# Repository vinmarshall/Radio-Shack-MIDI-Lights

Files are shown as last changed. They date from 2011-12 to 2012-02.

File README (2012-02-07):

These files are the plans for the "Radio Shack MIDI Lights" project 
that was featured in the December 2011 issue of Popular Science.  Look at 
the instructions file for more information.

./PCB - Circuit schematic and board layout.  
  Express PCB files plus images of the trace layers and mechanical drawings 
  of the board.

./midi_lights_code - Arduino code

./parts - Bill of Materials and parts sourcing information.

./schematic - The schematic for the circuit.

instructions.pdf - Instructions for building this project.

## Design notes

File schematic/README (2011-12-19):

These files are images of the schematic.  This information is the same as
the PCB/rs_midi_lights.sch file, presented here as a series of images.

Each image corresponds to one page on the schematic.

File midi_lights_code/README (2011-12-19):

Check the github repository for any updates, revisions, or bug fixes.
https://github.com/vinmarshall/Radio-Shack-MIDI-Lights 

midi_lights_code.pde - Arduino code for this project.

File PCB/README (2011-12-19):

The files in this directory pertain to the printed circuit board design.

Even if you don't choose to have your board professionally made, the mechanical
drawings, pictures of component placement, and the PDFs of the board layers
may help you in putting together your own board.  

I had my board made by ExpressPCB (great when you're in a hurry) and the board 
and schematic files here are in their program's format.

pcb_bottom_traces.pdf - The traces on the bottom side of the board.

pcb_components.bmp - How the components are laid out on top of the board.

pcb_dimensions.AD_DRW - Alibre CAD version of the pcb_dimensions.pdf 

pcb_dimensions.pdf - A mechanical drawing of the board with dimensions.

pcb_mechanical.dxf - DXF (2-D CAD) mechanical drawing of the board.

pcb_silkscreen.pdf - The silkscreen layer on top of the board.

pcb_top_traces.pdf - The traces on the top side of the board.

./PCBComponents_Custom - Custom components from this board for the ExpressPCB 
  software.

rs_midi_lights.pcb - ExpressPCB file with the board.

rs_midi_lights.sch - ExpressPCB file with the schematic.

./SchComponents_Custom - Custom components from this circuit for the ExpressPCB 
  software.

./SchSymbols_Custom - Custom symbols from this cicuit for the ExpressPCB software.

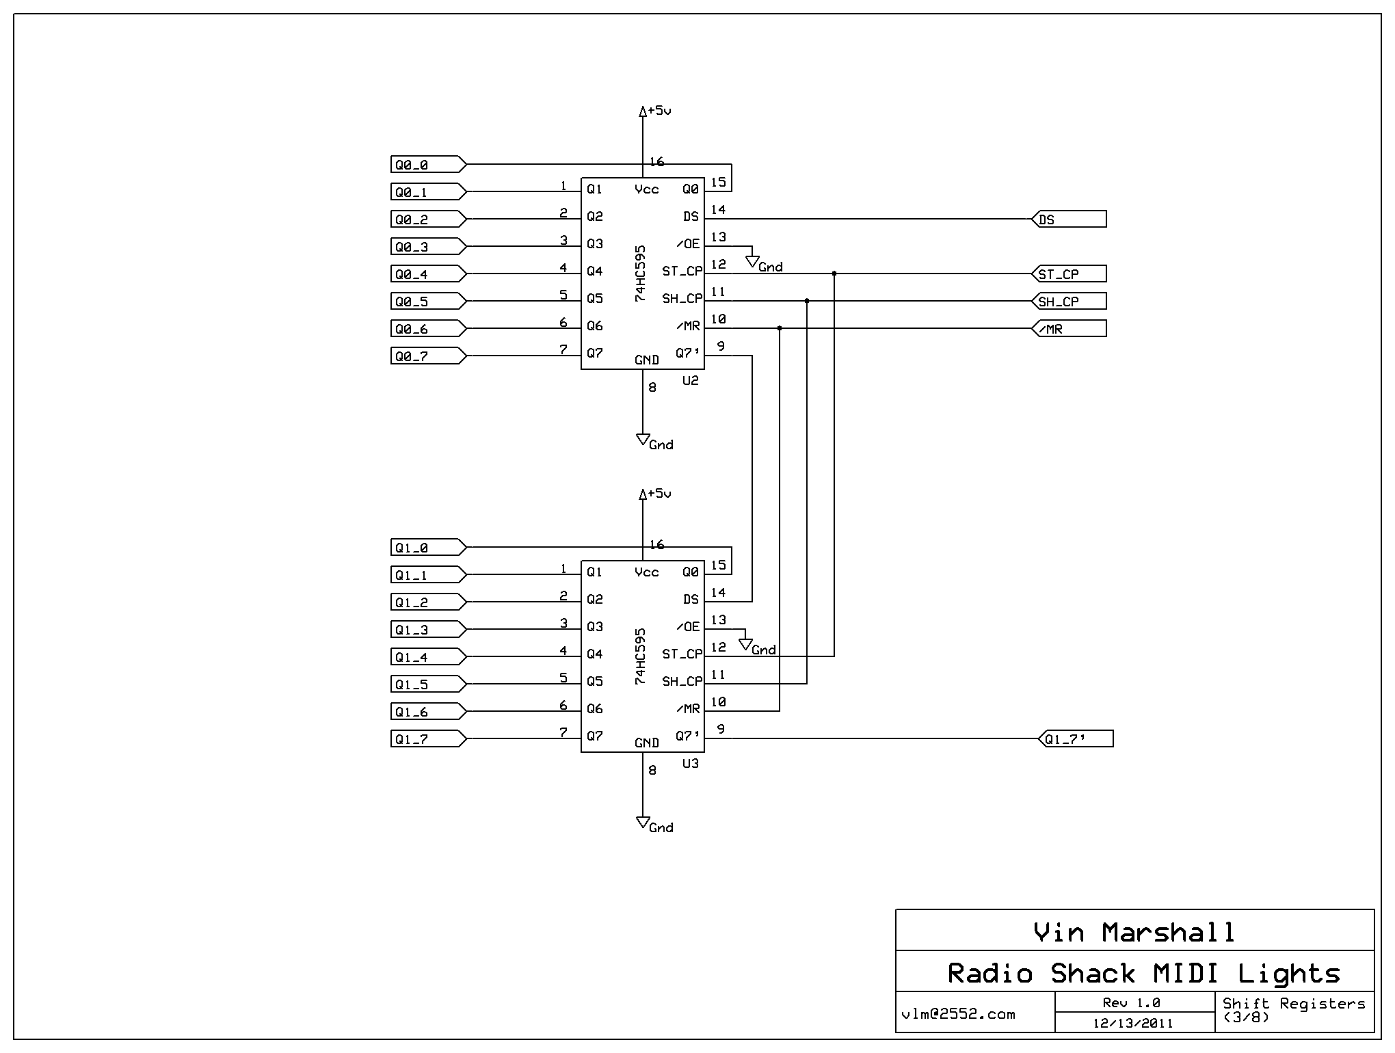
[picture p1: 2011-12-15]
schematic/3_shift_registers.bmp

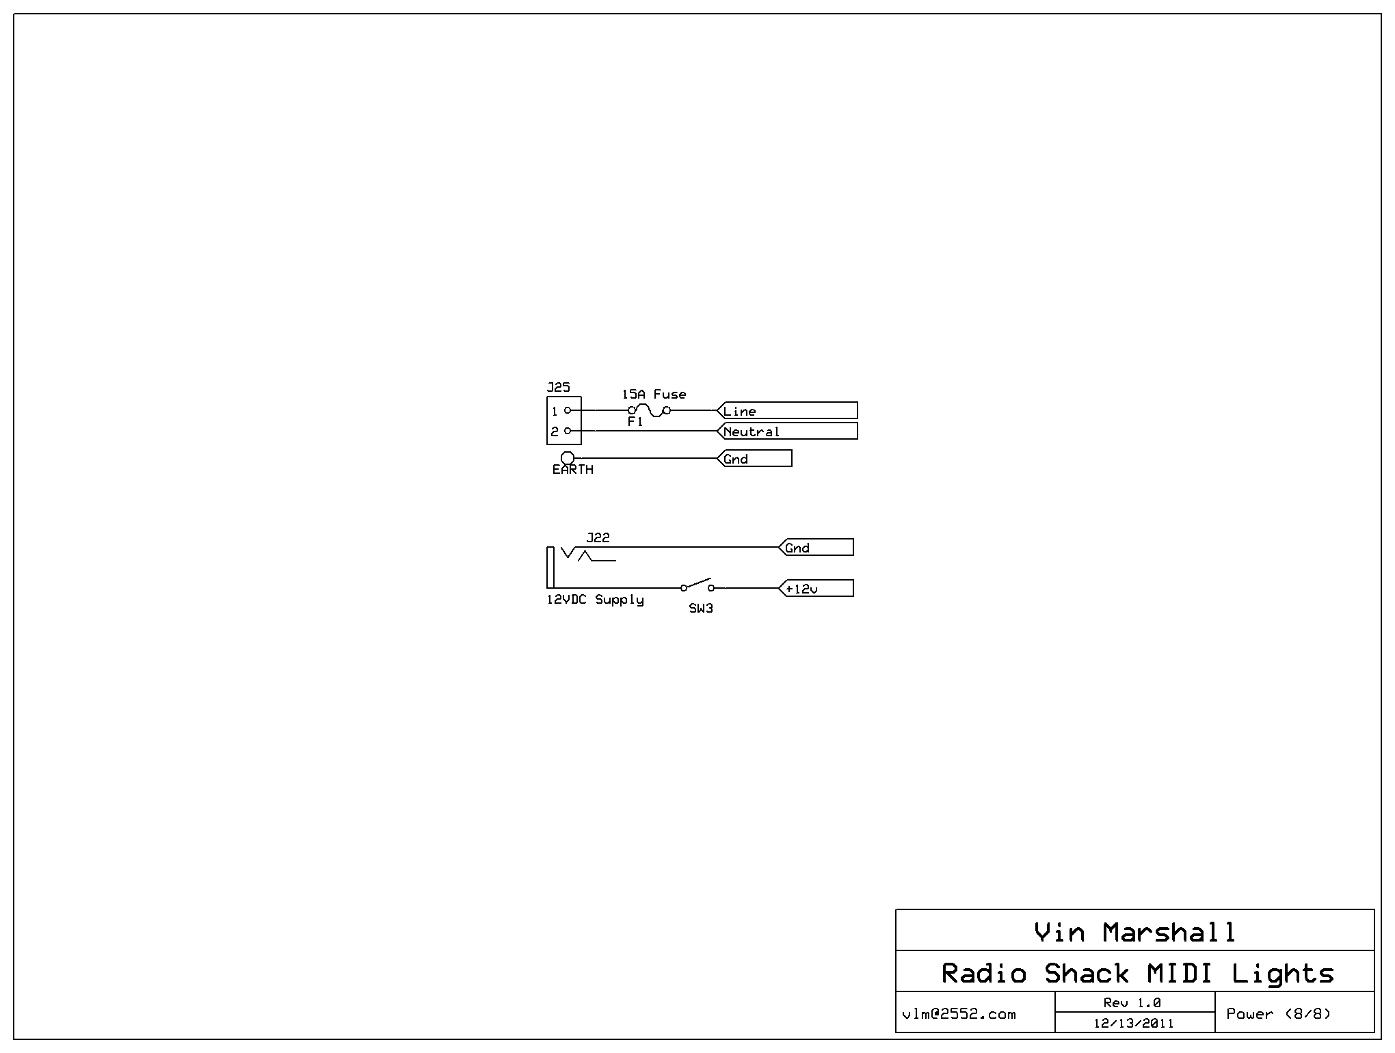
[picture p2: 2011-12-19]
schematic/8_power.bmp

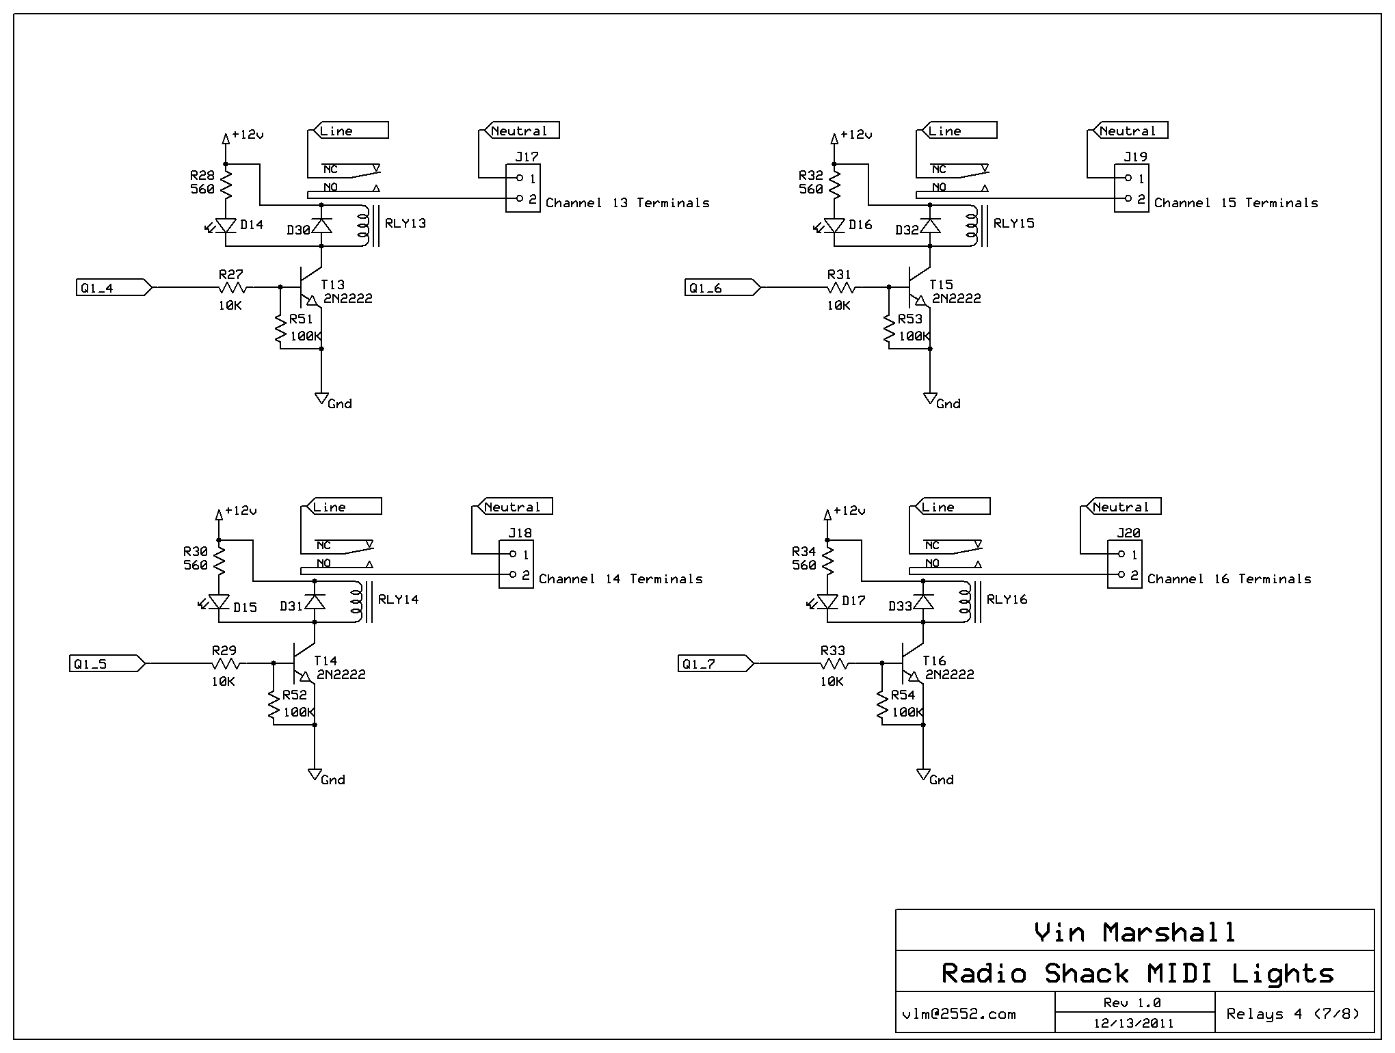
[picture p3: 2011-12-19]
schematic/7_relays_4.bmp

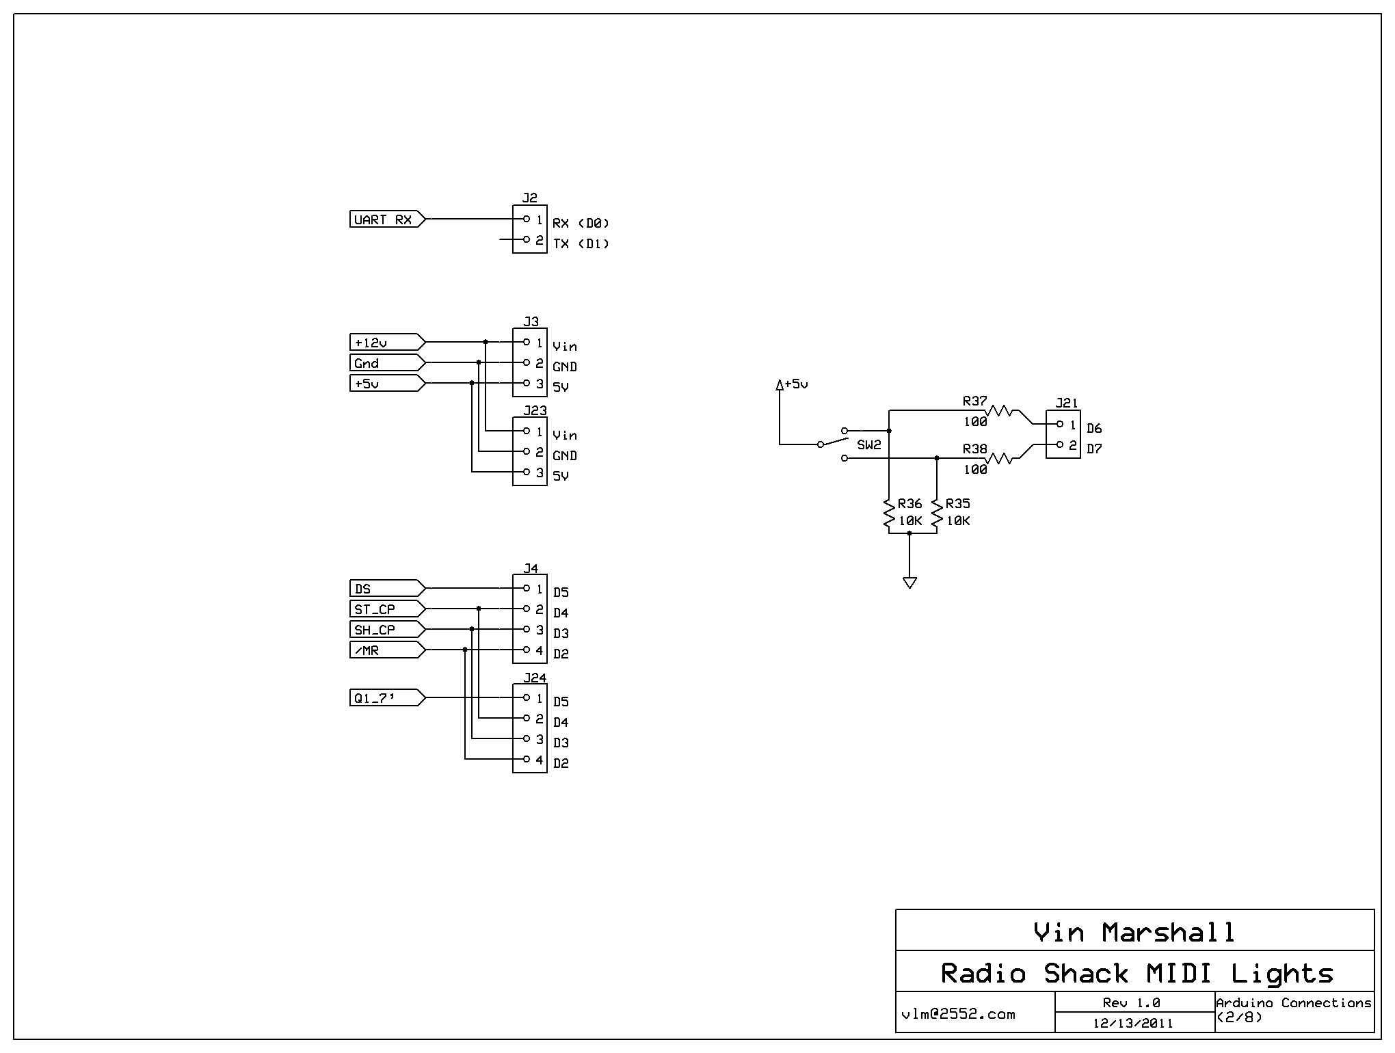
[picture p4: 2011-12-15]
schematic/2_arduino_connections.bmp

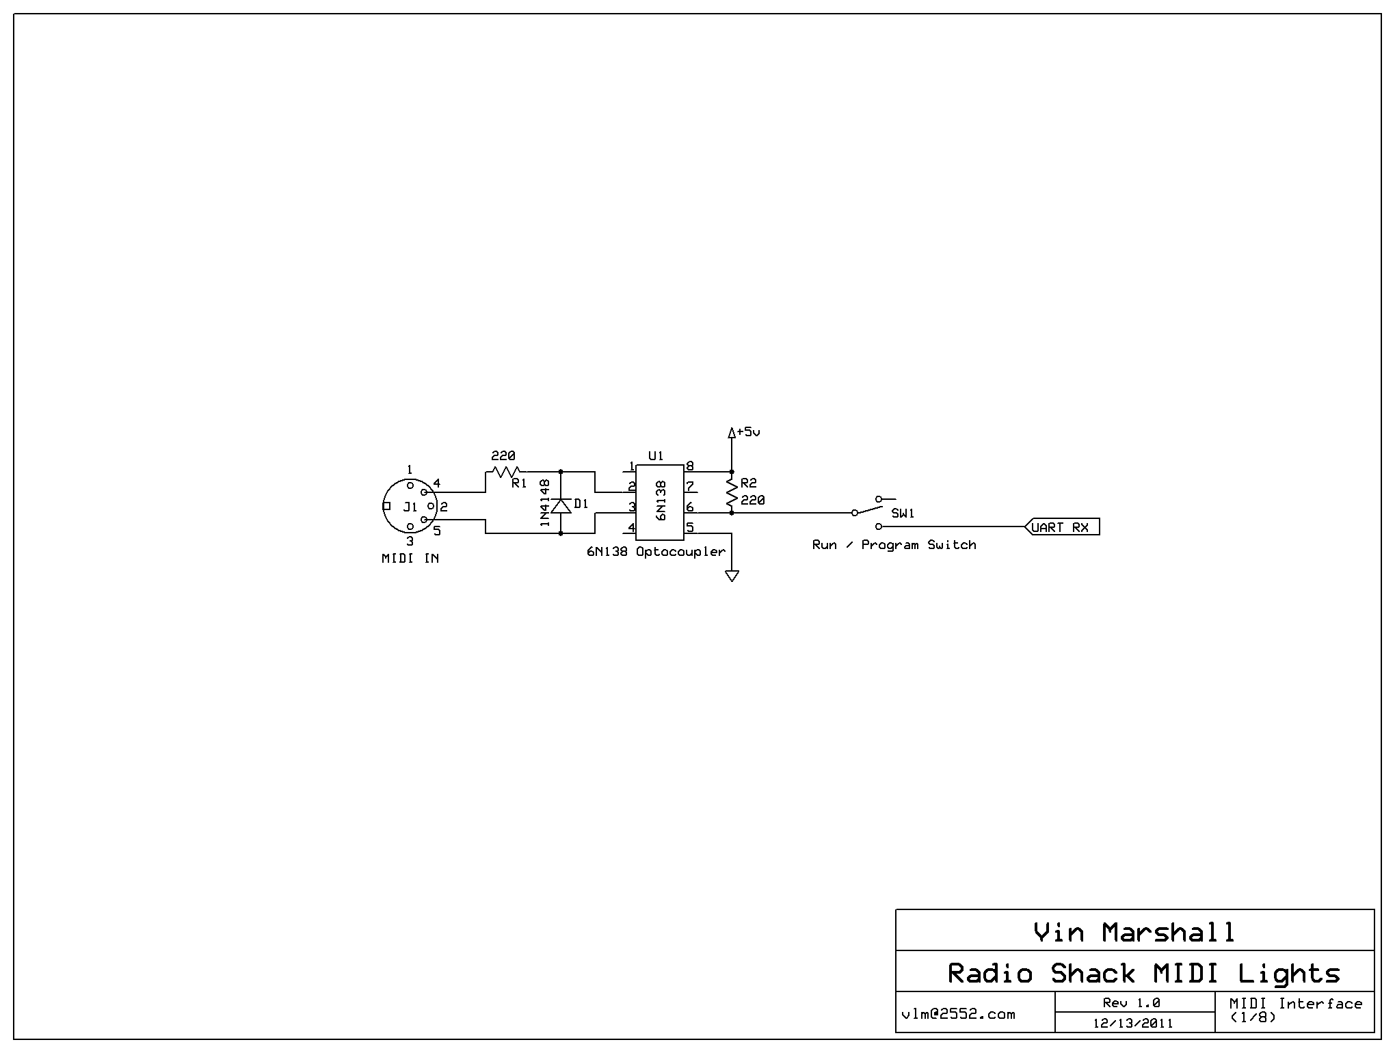
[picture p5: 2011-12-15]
schematic/1_MIDI.bmp

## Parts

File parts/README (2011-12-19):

The files in this directory contain information on sourcing parts for this 
project.  

circuit_board_BOM - A chart correlating part numbers on the schematic and 
  PCB to actual parts.

ordering_BOM - A Bill of Materials for ordering parts for this project.

PCB:

The PCB can be sourced from ExpressPCB.  For a board this big, they're not 
exactly cheap, but they are quick.  You may want to team up with a few other 
people building this circuit, as the unit price quickly goes down with quantity.

Instructions - 
 - Download their software from http://www.expresspcb.com/ if you don't already 
   have it.
 - Open the ./PCB/rs_midi_lights.pcb file
 - From the 'Layout' menu, select "Compute Board Cost" to see your options 
   (Standard or Proto) and then "Order Boards via the Internet" to order.

I've also included PDFs of the top, bottom, and silkscreen layers as well as a 
mechanical drawing of the board and a picture of the component placement which 
should be useful if you are laying out your own PCB or doing point to point 
wiring.

If you are going to doing this with point to point wiring on a perf board, you 
should be able to get this all to fit on 2 of Radio Shack p/n 276-147 - one
board for the relays and one for everything else.

ENCLOSURE:

I haven't specified a specific enclosure for this project, but make sure you 
enclose it completely in something to protect it from contamination, foreign 
objects, hands, etc... - especially if you choose to run 120VAC on the power
busses.  They CANNOT be left exposed.

PARTS:

The ordering_BOM file lists the parts I used to build the circuit and their
sources.  If you don't decide to build the project exactly as I did, the list
should at least give you a head start on your own build.

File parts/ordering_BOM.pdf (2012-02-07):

Sheet1

### Radio Shack MIDI Lights – Ordering Board Bill Of Materials

Quantity Part | Vendor | Part Number
1 | 1N4148 Diode | Radio Shack | 276-1122
8 | Red LED | Radio Shack | 276-0041
8 | 1N4004 Rectifier Diode | Radio Shack | 276-1103
4 | PC Board Terminals | Radio Shack | 276-1388
1 | 100 Ohm 1/4W Resistor | Radio Shack | 276-1311
1 | 220 Ohm 1/4W Resistor | Radio Shack | 271-1313
4 | 560 Ohm, 1/2W Resistor | Radio Shack | 271-1116
4 | 100K Ohm 1/4W Resistor | Radio Shack | 271-1347
5 | 10K Ohm 1/4W Resistor | Radio Shack | 271-1335
16 | 12VDC PC Mount Relay | Radio Shack | 275-241
1 | SPDT Center Off Toggle Switch | Radio Shack | 275-0325
1 | SPST Toggle Switch | Radio Shack | 275-0324
16 | 2N2222 NPN BJT Transistor | Radio Shack | 276-2009
1 | | Radio Shack | 276-128
1 | | Radio Shack | 276-138
1 | | Radio Shack | 273-318
1 | | Radio Shack | 273-342
1 | MIDI Connector | Spark Fun Electronics PRT-09536
1 | 0.1” Pin Headers | Spark Fun Electronics PRT-00116
2 | 2 Pin, 6” Jumper Wire | Spark Fun Electronics PRT-10367
1 | 3 Pin, 6” Jumper Wire | Spark Fun Electronics PRT-10368
1 | 4 Pin, 6” Jumper Wire | Spark Fun Electronics PRT-10369
1 | 2 Pin, 12” Jumper Wire | Spark Fun Electronics PRT-10372
1 | 3 Pin, 12” Jumper Wire | Spark Fun Electronics PRT-10373
1 | DC Power Connector | | CP-202A
1 | SPDT Slide Switch | | 450-1598
1 | 6N138 Optocoupler | | 6N138QT
2 | 74HC595 Shift Register | | 296-1600-5
1 | 9.52mm Terminal Blocks | | ED2677
1 | 15A Slow Blow Fuse | | F2649
1 | 15A PC Board Fuse Holder | | F1498

Sources:
Radio Shack
Spark Fun Electronics

Arduino Uno Rev 3
Arduino Maker Shield
Enercell DC Power Adapter
Enercell K Size Adaptaplug

DigiKey
DigiKey
DigiKey
DigiKey
DigiKey
DigiKey
DigiKey

www.radioshack.com
www.sparkfun.com
DigiKey | www.digikey.com

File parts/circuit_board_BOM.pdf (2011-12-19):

Sheet1

### Radio Shack MIDI Lights – Circuit Board Bill Of Materials

Part | Type | Name | Vendor and Part Number
D1 | Signal Diode | 1N4148 Diode | Radio Shack 276-1122
D2 | LED | Red LED | Radio Shack 276-041
D3 | LED | Red LED | Radio Shack 276-041
D4 | LED | Red LED | Radio Shack 276-041
D5 | LED | Red LED | Radio Shack 276-041
D6 | LED | Red LED | Radio Shack 276-041
D7 | LED | Red LED | Radio Shack 276-041
D8 | LED | Red LED | Radio Shack 276-041
D9 | LED | Red LED | Radio Shack 276-041
D10 | LED | Red LED | Radio Shack 276-041
D11 | LED | Red LED | Radio Shack 276-041
D12 | LED | Red LED | Radio Shack 276-041
D13 | LED | Red LED | Radio Shack 276-041
D14 | LED | Red LED | Radio Shack 276-041
D15 | LED | Red LED | Radio Shack 276-041
D16 | LED | Red LED | Radio Shack 276-041
D17 | LED | Red LED | Radio Shack 276-041
D18 | Rectifier Diode | 1N4004 | Radio Shack 276-1103
D19 | Rectifier Diode | 1N4004 | Radio Shack 276-1103
D20 | Rectifier Diode | 1N4004 | Radio Shack 276-1103
D21 | Rectifier Diode | 1N4004 | Radio Shack 276-1103
D22 | Rectifier Diode | 1N4004 | Radio Shack 276-1103
D23 | Rectifier Diode | 1N4004 | Radio Shack 276-1103
D24 | Rectifier Diode | 1N4004 | Radio Shack 276-1103
D25 | Rectifier Diode | 1N4004 | Radio Shack 276-1103
D26 | Rectifier Diode | 1N4004 | Radio Shack 276-1103
D27 | Rectifier Diode | 1N4004 | Radio Shack 276-1103
D28 | Rectifier Diode | 1N4004 | Radio Shack 276-1103
D29 | Rectifier Diode | 1N4004 | Radio Shack 276-1103
D30 | Rectifier Diode | 1N4004 | Radio Shack 276-1103
D31 | Rectifier Diode | 1N4004 | Radio Shack 276-1103
D32 | Rectifier Diode | 1N4004 | Radio Shack 276-1103
D33 | Rectifier Diode | 1N4004 | Radio Shack 276-1103
F1 | Fuse | 15A Fuse
J1 | Connector | MIDI IN
J2 | Connector | 0.1" Pin Headers
J3 | Connector | 0.1" Pin Headers
J4 | Connector | 0.1" Pin Headers
J5 | Connector | Channel 1 Terminals | Radio Shack 276-1388
J6 | Connector | Channel 2 Terminals | Radio Shack 276-1388
J7 | Connector | Channel 3 Terminals | Radio Shack 276-1388
J8 | Connector | Channel 4 Terminals | Radio Shack 276-1388
J9 | Connector | Channel 5 Terminals | Radio Shack 276-1388
J10 | Connector | Channel 6 Terminals | Radio Shack 276-1388
J11 | Connector | Channel 7 Terminals | Radio Shack 276-1388
J12 | Connector | Channel 8 Terminals | Radio Shack 276-1388
J13 | Connector | Channel 9 Terminals | Radio Shack 276-1388
J14 | Connector | Channel 10 Terminals | Radio Shack 276-1388
J15 | Connector | Channel 11 Terminals | Radio Shack 276-1388

Digikey F1498, F2649
Sparkfun PRT-09536
Sparkfun PRT-00116
Sparkfun PRT-00116
Sparkfun PRT-00116

Page

2

J16 | Connector | Channel 12 Terminals | Radio Shack 276-1388
J17 | Connector | Channel 13 Terminals | Radio Shack 276-1388
J18 | Connector | Channel 14 Terminals | Radio Shack 276-1388
J19 | Connector | Channel 15 Terminals | Radio Shack 276-1388
J20 | Connector | Channel 16 Terminals | Radio Shack 276-1388
J21 | Connector | 0.1" Pin Headers
J22 | Connector | 12VDC Supply
J23 | Connector | 0.1" Pin Headers
J24 | Connector | 0.1" Pin Headers
J25 | Connector | Lighting Power Input
R1 | Resistor (1/4W) | 220 | Radio Shack 271-1313
R2 | Resistor (1/4W) | 220 | Radio Shack 271-1313
R3 | Resistor (1/4W) | 10K | Radio Shack 271-1335
R4 | Resistor (1/2W) | 560 | Radio Shack 271-1116
R5 | Resistor (1/4W) | 10K | Radio Shack 271-1335
R6 | Resistor (1/2W) | 560 | Radio Shack 271-1116
R7 | Resistor (1/4W) | 10K | Radio Shack 271-1335
R8 | Resistor (1/2W) | 560 | Radio Shack 271-1116
R9 | Resistor (1/4W) | 10K | Radio Shack 271-1335
R10 | Resistor (1/2W) | 560 | Radio Shack 271-1116
R11 | Resistor (1/4W) | 10K | Radio Shack 271-1335
R12 | Resistor (1/2W) | 560 | Radio Shack 271-1116
R13 | Resistor (1/4W) | 10K | Radio Shack 271-1335
R14 | Resistor (1/4W) | 220 | Radio Shack 271-1313
R15 | Resistor (1/4W) | 10K | Radio Shack 271-1335
R16 | Resistor (1/2W) | | Radio Shack 271-1116
R17 | Resistor (1/4W) | 10K | Radio Shack 271-1335
R18 | Resistor (1/2W) | 560 | Radio Shack 271-1116
R19 | Resistor (1/4W) | 10K | Radio Shack 271-1335
R20 | Resistor (1/2W) | 560 | Radio Shack 271-1116
R21 | Resistor (1/4W) | 10K | Radio Shack 271-1335
R22 | Resistor (1/2W) | 560 | Radio Shack 271-1116
R23 | Resistor (1/4W) | 10K | Radio Shack 271-1335
R24 | Resistor (1/2W) | 560 | Radio Shack 271-1116
R25 | Resistor (1/4W) | 10K | Radio Shack 271-1335
R26 | Resistor (1/2W) | 560 | Radio Shack 271-1116
R27 | Resistor (1/4W) | 10K | Radio Shack 271-1335
R28 | Resistor (1/2W) | 560 | Radio Shack 271-1116
R29 | Resistor (1/4W) | 10K | Radio Shack 271-1335
R30 | Resistor (1/2W) | 560 | Radio Shack 271-1116
R31 | Resistor (1/4W) | 10K | Radio Shack 271-1335
R32 | Resistor (1/2W) | 560 | Radio Shack 271-1116
R33 | Resistor (1/4W) | 10K | Radio Shack 271-1335
R34 | Resistor (1/2W) | 560 | Radio Shack 271-1116
R35 | Resistor (1/4W) | 10K | Radio Shack 271-1335
R36 | Resistor (1/4W) | 10K | Radio Shack 271-1335
R37 | Resistor (1/4W) | 100 | Radio Shack 271-1311
R38 | Resistor (1/4W) | 100 | Radio Shack 271-1311
R39 | Resistor (1/4W) | 100K | Radio Shack 271-1347
R40 | Resistor (1/4W) | 100K | Radio Shack 271-1347
R41 | Resistor (1/4W) | 100K | Radio Shack 271-1347
R42 | Resistor (1/4W) | 100K | Radio Shack 271-1347

Sparkfun PRT-00116
Digikey CP-202A-ND
Sparkfun PRT-00116
Sparkfun PRT-00116
Digikey ED2677

560

R43 | Resistor (1/4W) | 100K | Radio Shack 271-1347
R44 | Resistor (1/4W) | 100K | Radio Shack 271-1347
R45 | Resistor (1/4W) | 100K | Radio Shack 271-1347
R46 | Resistor (1/4W) | 100K | Radio Shack 271-1347
R47 | Resistor (1/4W) | 100K | Radio Shack 271-1347
R48 | Resistor (1/4W) | 100K | Radio Shack 271-1347
R49 | Resistor (1/4W) | 100K | Radio Shack 271-1347
R50 | Resistor (1/4W) | 100K | Radio Shack 271-1347
R51 | Resistor (1/4W) | 100K | Radio Shack 271-1347
R52 | Resistor (1/4W) | 100K | Radio Shack 271-1347
R53 | Resistor (1/4W) | 100K | Radio Shack 271-1347
R54 | Resistor (1/4W) | 100K | Radio Shack 271-1347
RLY1 | Relay | 12VDC Relay | Radio Shack 275-241
RLY2 | Relay | 12VDC Relay | Radio Shack 275-241
RLY3 | Relay | 12VDC Relay | Radio Shack 275-241
RLY4 | Relay | 12VDC Relay | Radio Shack 275-241
RLY5 | Relay | 12VDC Relay | Radio Shack 275-241
RLY6 | Relay | 12VDC Relay | Radio Shack 275-241
RLY7 | Relay | 12VDC Relay | Radio Shack 275-241
RLY8 | Relay | 12VDC Relay | Radio Shack 275-241
RLY9 | Relay | 12VDC Relay | Radio Shack 275-241
RLY10 Relay | 12VDC Relay | Radio Shack 275-241
RLY11 Relay | 12VDC Relay | Radio Shack 275-241
RLY12 Relay | 12VDC Relay | Radio Shack 275-241
RLY13 Relay | 12VDC Relay | Radio Shack 275-241
RLY14 Relay | 12VDC Relay | Radio Shack 275-241
RLY15 Relay | 12VDC Relay | Radio Shack 275-241
RLY16 Relay | 12VDC Relay | Radio Shack 275-241
SW1 | Switch | Run / Program Switch
SW2 | Switch | SPDT Center Off Toggle Switch Radio Shack 275-0325
SW3 | Switch | SPST Toggle Switch | Radio Shack 275-0324
T1 | Transistor | 2N2222 | Radio Shack 276-2009
T2 | Transistor | 2N2222 | Radio Shack 276-2009
T3 | Transistor | 2N2222 | Radio Shack 276-2009
T4 | Transistor | 2N2222 | Radio Shack 276-2009
T5 | Transistor | 2N2222 | Radio Shack 276-2009
T6 | Transistor | 2N2222 | Radio Shack 276-2009
T7 | Transistor | 2N2222 | Radio Shack 276-2009
T8 | Transistor | 2N2222 | Radio Shack 276-2009
T9 | Transistor | 2N2222 | Radio Shack 276-2009
T10 | Transistor | 2N2222 | Radio Shack 276-2009
T11 | Transistor | 2N2222 | Radio Shack 276-2009
T12 | Transistor | 2N2222 | Radio Shack 276-2009
T13 | Transistor | 2N2222 | Radio Shack 276-2009
T14 | Transistor | 2N2222 | Radio Shack 276-2009
T15 | Transistor | 2N2222 | Radio Shack 276-2009
T16 | Transistor | 2N2222 | Radio Shack 276-2009
U1 | IC | 6N138 Optocoupler
U2 | IC | 74HC595 Shift Register
U3 | IC | 74HC595 Shift Register

Digikey 450-1598-ND

Digikey 6N138QT-ND
Digikey 296-1600-5-ND
Digikey 296-1600-5-ND

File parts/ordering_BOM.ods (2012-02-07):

Radio Shack MIDI Lights – Ordering Board Bill Of Materials
Quantity | Part | Vendor | Part Number
1 | 1N4148 Diode | Radio Shack | 276-1122
8 | Red LED | Radio Shack | 276-0041
8 | 1N4004 Rectifier Diode | Radio Shack | 276-1103
4 | PC Board Terminals | Radio Shack | 276-1388
1 | 100 Ohm 1/4W Resistor | Radio Shack | 276-1311
1 | 220 Ohm 1/4W Resistor | Radio Shack | 271-1313
4 | 560 Ohm, 1/2W Resistor | Radio Shack | 271-1116
4 | 100K Ohm 1/4W Resistor | Radio Shack | 271-1347
5 | 10K Ohm 1/4W Resistor | Radio Shack | 271-1335
16 | 12VDC PC Mount Relay | Radio Shack | 275-241
1 | SPDT Center Off Toggle Switch | Radio Shack | 275-0325
1 | SPST Toggle Switch | Radio Shack | 275-0324
16 | 2N2222 NPN BJT Transistor | Radio Shack | 276-2009
1 | Arduino Uno Rev 3 | Radio Shack | 276-128
1 | Arduino Maker Shield | Radio Shack | 276-138
1 | Enercell DC Power Adapter | Radio Shack | 273-318
1 | Enercell K Size Adaptaplug | Radio Shack | 273-342
1 | MIDI Connector | Spark Fun Electronics | PRT-09536
1 | 0.1” Pin Headers | Spark Fun Electronics | PRT-00116
2 | 2 Pin, 6” Jumper Wire | Spark Fun Electronics | PRT-10367
1 | 3 Pin, 6” Jumper Wire | Spark Fun Electronics | PRT-10368
1 | 4 Pin, 6” Jumper Wire | Spark Fun Electronics | PRT-10369
1 | 2 Pin, 12” Jumper Wire | Spark Fun Electronics | PRT-10372
1 | 3 Pin, 12” Jumper Wire | Spark Fun Electronics | PRT-10373
1 | DC Power Connector | DigiKey | CP-202A
1 | SPDT Slide Switch | DigiKey | 450-1598
1 | 6N138 Optocoupler | DigiKey | 6N138QT
2 | 74HC595 Shift Register | DigiKey | 296-1600-5
1 | 9.52mm Terminal Blocks | DigiKey | ED2677
1 | 15A Slow Blow Fuse | DigiKey | F2649
1 | 15A PC Board Fuse Holder | DigiKey | F1498
Sources:
Radio Shack |  | www.radioshack.com
Spark Fun Electronics |  | www.sparkfun.com
DigiKey |  | www.digikey.com

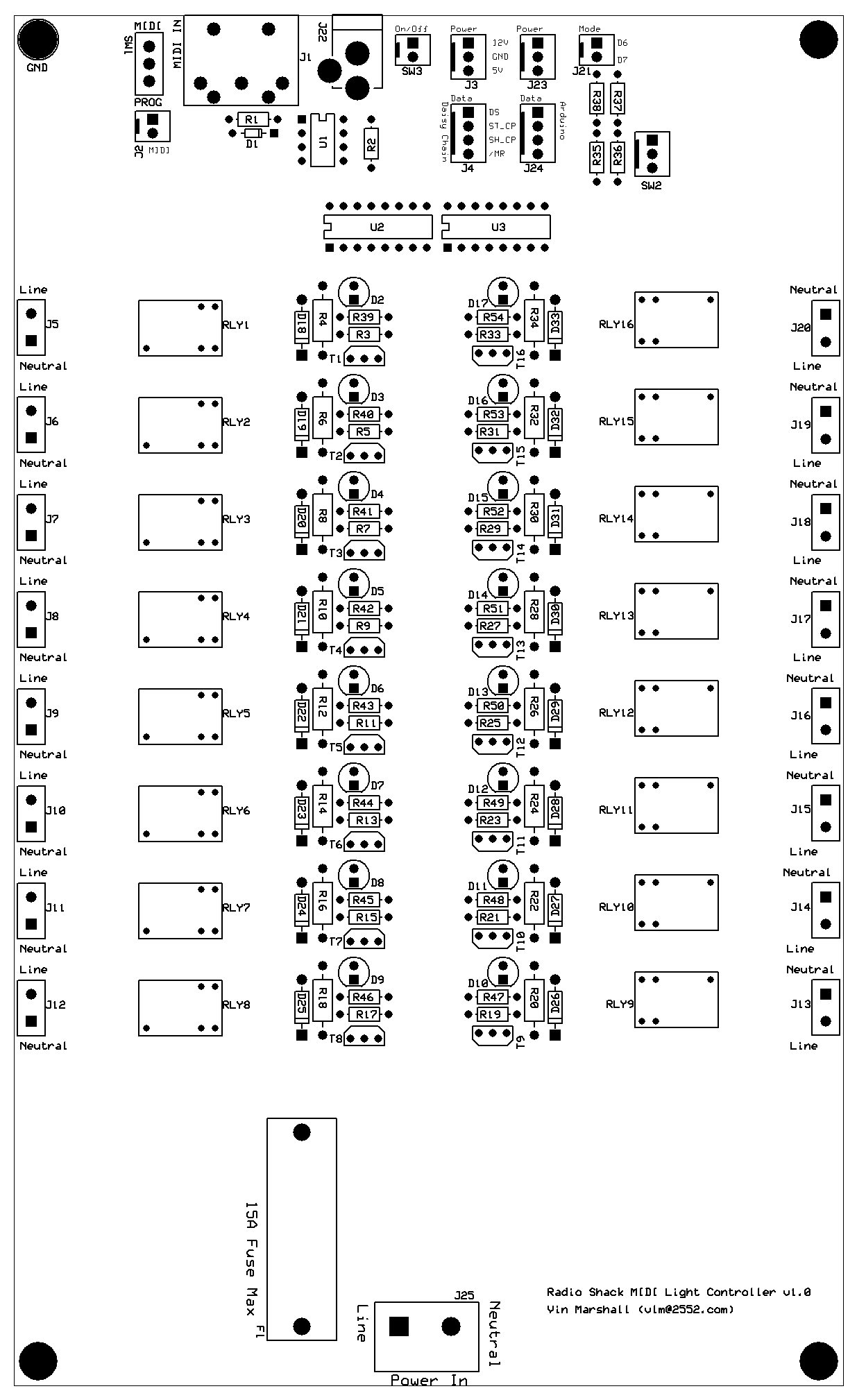
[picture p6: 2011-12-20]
PCB/pcb_components.bmp

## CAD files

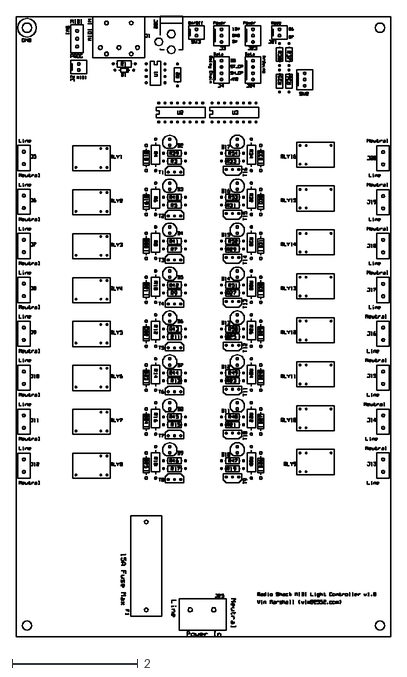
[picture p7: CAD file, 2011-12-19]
PCB/pcb_mechanical.dxf
5.97 x 9.88

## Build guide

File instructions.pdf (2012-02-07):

## MIDI Lights

Version 1.0
Vin Marshall (vlm@2552.com) www.te-motorworks.com

Parts For This Project

Quantity Part | Vendor | Part Number
1 | 1N4148 Diode | Radio Shack | 276-1122
8 | Red LED | Radio Shack | 276-0041
8 | 1N4004 Rectifier Diode | Radio Shack | 276-1103
4 | PC Board Terminals | Radio Shack | 276-1388
1 | 100 Ohm 1/4W Resistor | Radio Shack | 276-1311
1 | 220 Ohm 1/4W Resistor | Radio Shack | 271-1313
4 | 560 Ohm, 1/2W Resistor | Radio Shack | 271-1116
4 | 100K Ohm 1/4W Resistor | Radio Shack | 271-1347
5 | 10K Ohm 1/4W Resistor | Radio Shack | 271-1335
16 | 12VDC PC Mount Relay | Radio Shack | 275-241
1 | SPDT Center Off Toggle Switch | Radio Shack | 275-0325
1 | SPST Toggle Switch | Radio Shack | 275-0324
16 | 2N2222 NPN BJT Transistor | Radio Shack | 276-2009
1 | Arduino Uno Rev 3 | Radio Shack | 276-128
1 | Arduino Maker Shield | Radio Shack | 276-138
1 | Enercell DC Power Adapter | Radio Shack | 273-318
1 | Enercell K Size Adaptaplug | Radio Shack | 273-342
1 | MIDI Connector | Spark Fun Electronics PRT-09536
1 | 0.1” Pin Headers | Spark Fun Electronics PRT-00116
2 | 2 Pin, 6” Jumper Wire | Spark Fun Electronics PRT-10367
1 | 3 Pin, 6” Jumper Wire | Spark Fun Electronics PRT-10368
1 | 4 Pin, 6” Jumper Wire | Spark Fun Electronics PRT-10369
1 | 2 Pin, 12” Jumper Wire | Spark Fun Electronics PRT-10372
1 | 3 Pin, 12” Jumper Wire | Spark Fun Electronics PRT-10373
1 | DC Power Connector | DigiKey | CP-202A
1 | SPDT Slide Switch | DigiKey | 450-1598
1 | 6N138 Optocoupler | DigiKey | 6N138QT
2 | 74HC595 Shift Register | DigiKey | 296-1600-5
1 | 9.52mm Terminal Blocks | DigiKey | ED2677
1 | 15A Slow Blow Fuse | DigiKey | F2649
1 | 15A PC Board Fuse Holder | DigiKey | F1498

Assembly Instructions
Introduction:
This project is a MIDI synthesizer of sorts, in that it receives and interprets MIDI messages, but those messages are translated to light rather than sound. 16 notes centered around middle C are mapped to 16 banks of lights – when a note is played, the corresponding relay turns on.
It can run in a standalone mode in which it loops over a previously recorded sequence, or it can play live from a connected instrument. It can even be connected to a sequencer, “playing” the lights in sync with the performance as one instrument in an arrangement.

WARNING: It is strongly recommended that you use this project to control low voltage lighting only, unless you are highly experienced in working with circuits and circuit boards that use 120VAC mains power. Use of mains power involves significant risk. It can potentially hurt or kill you, start fires, etc...

All of the supporting files for this project can be downloaded from: https://github.com/vinmarshall/Radio-Shack-MIDI-Lights/zipball/master

Step 1: Build the Circuit Board

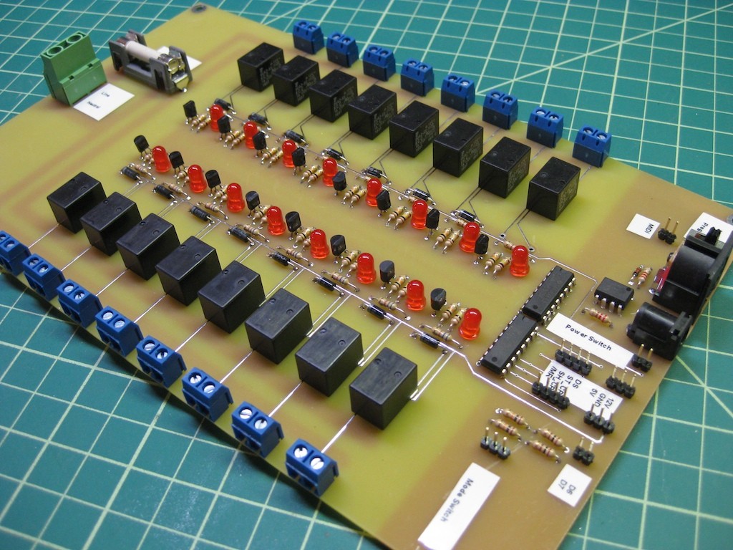
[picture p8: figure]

Before building the circuit board, take a minute to study the schematic for this project, which is in the ./schematic directory of the download. Understanding the schematic will make the circuit much easier to test and debug. Each file corresponds to one section of the circuit. The connections between them are shown with busses, like the +12V, Gnd, and DS busses.
The parts needed to build this circuit are listed in the ./parts directory of the download. The ordering_BOM file lists the parts to order and the circuit_board_BOM file shows where to place those components on the circuit board.
There are several options for sourcing the printed circuit board itself:
- Order it from ExpressPCB.com using their free software (windows only) and the ./PCB/rs_midi_lights.pcb file. There is a minimum order of 2.
- Order it from me (vlm@2552.com).
- Etch the board yourself – either use the PDFs of the top, bottom, and silkscreen layers from the ./PCB directory or design your own board.
- Do point to point wiring using something like Radio Shack p/n 276-147 – you'll probably need 2.
If you chose to make your own PCB or do point to point wiring, pay careful attention to the size and separation of the traces to carry the lighting power. The circuit and PCB have only been designed and tested as specified in the rs_midi_lights.sch and rs_midi_lights.pcb files.

Step 2: Program the Arduino

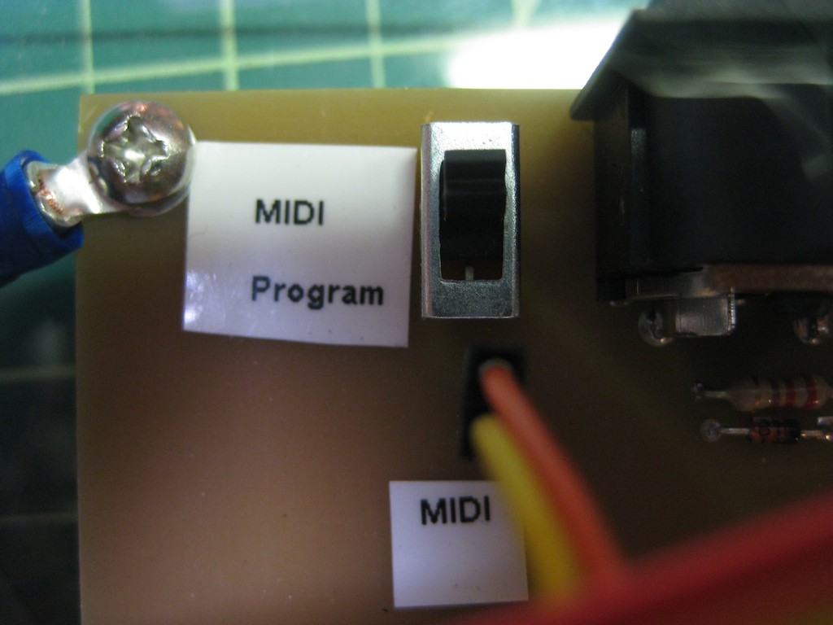
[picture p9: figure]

If you don't already have it, download the Arduino software from http://www.arduino.cc/.
Open the Arduino software and connect the Arduino to your computer via USB. Under the “Tools” drop down menu, select your board type (Arduino UNO for this project) and serial port (/dev/tty.usbmodem***).
Load the MIDI Light Controller software from the ./midi_lights_code directory of the project download and program your Arduino.
If you have any problems with connecting and programming the Arduino, consult the help available in the Arduino forums at http://arduino.cc/forum/.
If you want to program the Arduino again after you've connected it to the MIDI lights circuit (1) make sure the lighting power is disconnected and (2) set the MIDI / PROG switch located next to the MIDI connector to Program. Switch it back to MIDI after programming is complete.

Step 3: Connect the Circuit Board

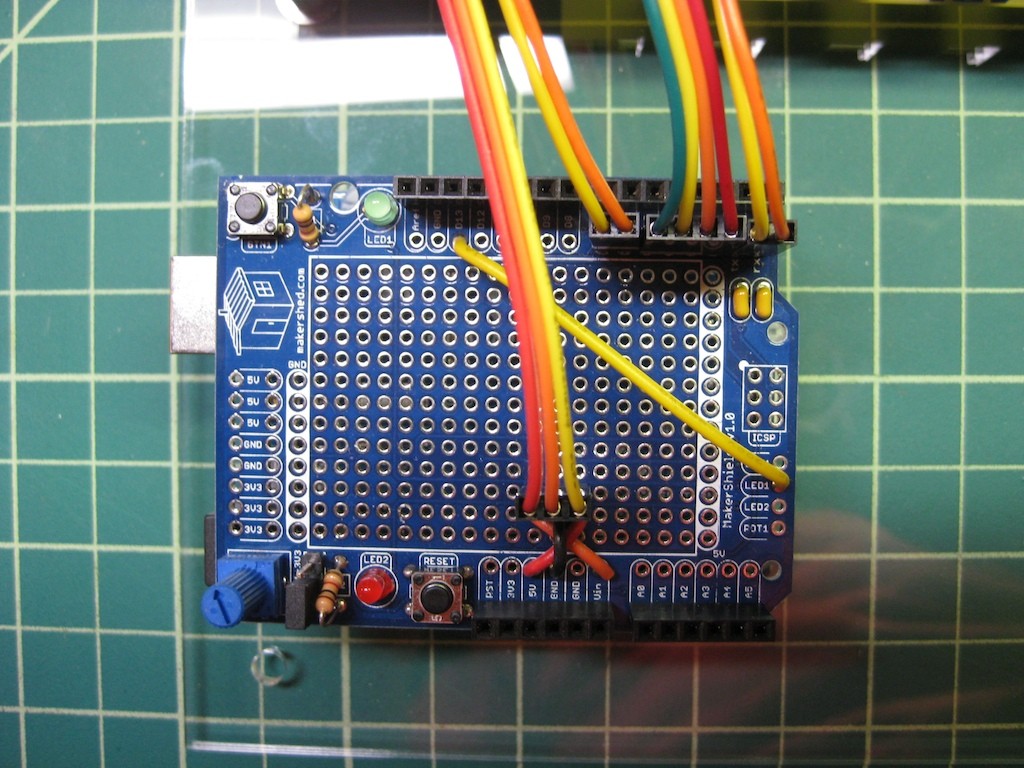
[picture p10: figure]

The circuit board is connected to the Arduino by a series of jumpers. A “maker shield” is placed on top of the Arduino to make the connections for these jumpers. The jumpers plug into 0.1” headers.
Wire Arduino pin D13 to the maker shield pin “LED 1”.
Wire three pins for a Power connection as follows:
Arduino | PCB | Jumper
Vin | 12V | 3 wire 6” jumper
GND | GND
5V | 5V

Solder pins to Arduino D1-D8 for connection as follows:

Arduino | PCB | Jumper
D0 (RX) | MIDI IN | 2 wire 6” jumper
D1 (TX) | Not Connected
D2 | /MR | 4 wire 6” jumper
D3 | SH_CP
D4 | ST_CP
D5 | DS
D6 | D6 | 2 wire 6” jumper
D7 | D7

Step 4: More Wiring

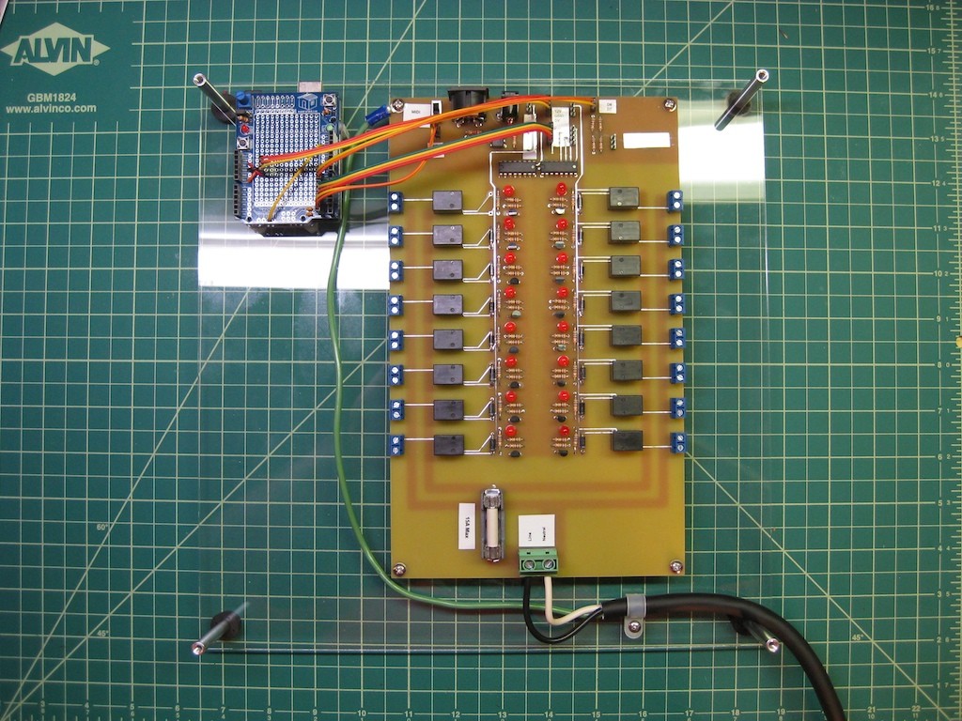
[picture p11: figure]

Switches and a lighting power supply also need to be connected to the circuit board.
The switches are easy:
- Cut one end off of a 2 wire, 12” jumper and solder it to the SPST toggle. Connect the other end to the power switch headers on the PCB.
- Cut one end off of a 3 wire, 12” jumper and solder it to the SPDT toggle. Connect the other end to the mode switch headers on the PCB.
The lighting power supply is a bit more complicated. The circuit is set up to provide power to each pair of terminals when the corresponding relay is activated. The lighting power is connected to the set of terminals at the bottom of the board, in the center.
DO NOT connect to any kind of power yet. Read the following before deciding what power to connect to this circuit:
I recommend the use of low voltage lighting with this project. Remember that
mains power can potentially burn down your house, kill you - that kind of thing.
Only consider using 120VAC with this project if you are comfortable not only in your ability to safely build and operate a project using mains power, but
also in your ability to examine the circuit schematic and the circuit board
to verify that it is suitable for this use and meets all applicable standards
and regulations in your area. The project isn't a finished consumer product and it shouldn't be treated as such.
Make sure you have thought through and checked the circuit, the board, and all
of your wiring and connections to it BEFORE you connect power to this project.
It is ultimately your responsibility to do this safely.
If you are using low voltage DC, connect the (+) lead to the power terminal at the bottom of the board marked "Line" and the (-) lead to the terminal marked "Neutral". Observe the same convention at each of the output terminals as you connect the lighting. Note that the orientation is reversed on the left and right sides of the board.
If you are using 120VAC, connect the black, or hot, leg to the power input terminal at the bottom of the board marked "Line" and the white, or neutral, leg to the terminal marked "Neutral". Observe the same convention at each of the output terminals as you connect the lighting. Note that the orientation is reversed on the left and right sides of the board.
Use a 3AG fuse no larger than 15A in the fuse holder. Size the fuse's rating to your circuit's expected current draw. The relays are rated for 1A maximum at 120VAC or 24VDC.
The Ground from the lighting power source should be attached under the mounting screw at the top left of the circuit board, as pictured above. The chassis ground from your enclosure should also be attached to this point. Grounding the circuit is very important.

Step 5: Testing

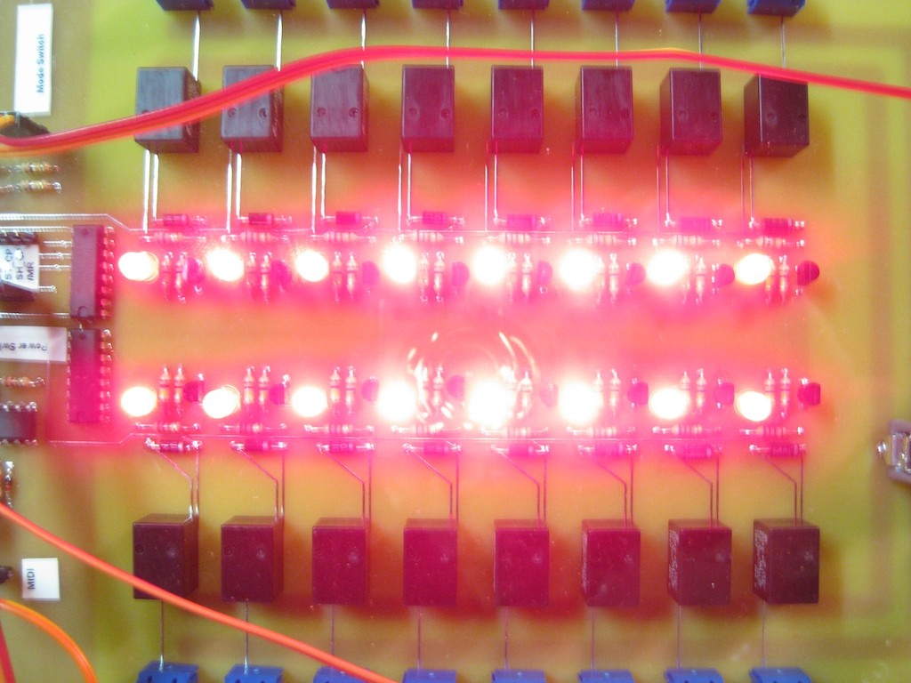
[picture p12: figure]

Do this step BEFORE making any connections to the relay screw terminals. The lighting power source should NOT be connected yet.
Install the barrel tip on the power supply such that the sleeve of the barrel (outside) is negative and the tip (inside) is positive. Connect the 12V power to the barrel jack at the top of the PCB.
Attach a MIDI keyboard and power up the circuit. You should hear all of the relays click 3 times. Put the mode switch in "Live" (center position) and verify that the notes you are playing on the keyboard are being translated into relays turning on and off. You can see which relays are active because the corresponding LEDs will also be lit.
If things are not going smoothly, there are a number of debug modes that can be enabled to assist in troubleshooting. Look at the Arduino code for more detail.

Step 6: Mount the Circuit

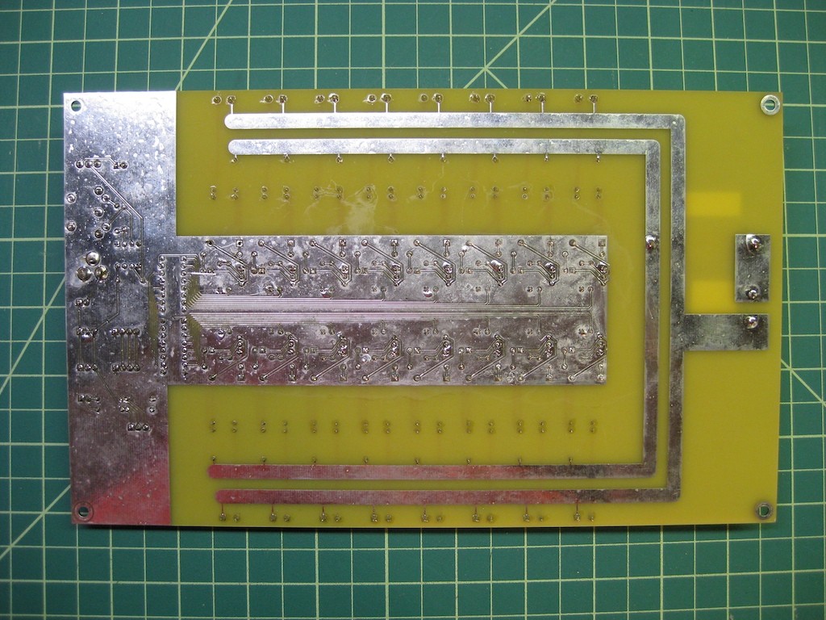
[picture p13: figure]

Because of the power traces on the circuit board, it needs to be mounted securely inside a suitable enclosure. A suitable enclosure will isolate and protect the component leads and wiring / traces on the board from any contact with contaminants, foreign objects, body parts, and any conductive part of the enclosure. The board should be isolated by at least 1 inch from anything conductive.
This board and this circuit are NOT designed to be used outside or in any kind of harsh environment.
The arcylic setup in my pictures is NOT an acceptable enclosure – I'm using it only for demonstration purposes. It is not acceptable because it does not protect against intrusion from foreign objects that might come in contact with the power traces.
The chassis ground from the enclosure should be attached to the top left mounting screw of the PCB, along with the ground from the lighting power supply.

Step 7: Power Dongles (Optional)

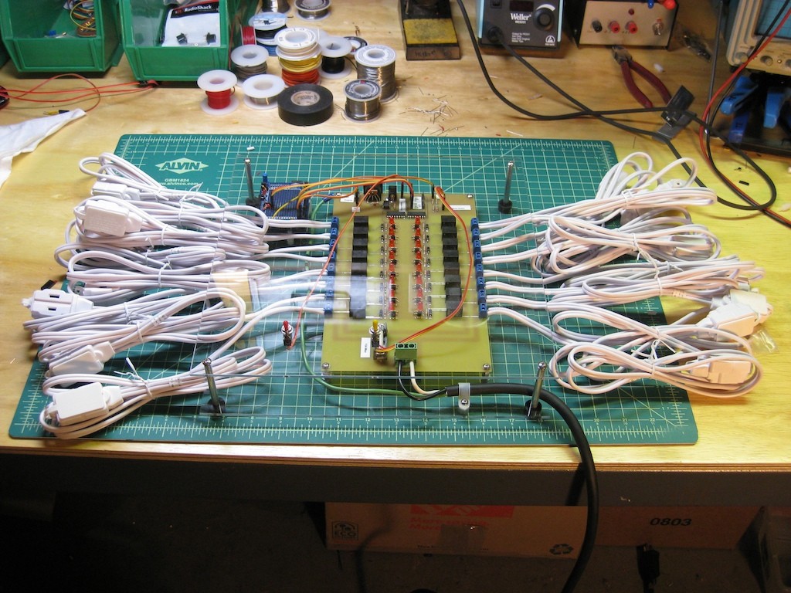
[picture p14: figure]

I used cheap extension cords from Home Depot (SKU# 144983, $1.47 each) to connect my lighting. This allows you to bring the power to the lighting rather than routing all of the lights back to the MIDI Light Controller.
To prepare these dongles, cut off the plugs, strip about 1/4” of insulation from both leads, and tin them with solder. Keep the solder minimal so that they will still fit into the screw terminals. These cords are polarized. The wire that connects to the narrow plug slot is the Line (hot) conductor. Make sure that hot wire gets connected to the Line side of the screw terminals. Note that the orientation of the Line / Neutral terminals is reversed on the right and left sides of the board. Refer to the silkscreen layer for markings.

Check the Github repository for the most recent version of this document: https://github.com/vinmarshall/Radio-Shack-MIDI-Lights
DISCLAIMER: This project is not a consumer product; it is just one hobbyist sharing his plans. It is provided "AS IS" without warranty of any kind, either expressed or implied, including, but not limited to the implied warranties of merchantability and fitness for a particular purpose. You are building and operating this at your own risk.
If you are going to use this project to switch mains power, you must be aware of and in compliance with UL 60950-1, UL 62368, IPC-2221A, and any and all other relevant or applicable standards. Please do not attempt to use this to switch mains power if you do not possess sufficient experience to do so safely.
Copyright 2012 Vin Marshall

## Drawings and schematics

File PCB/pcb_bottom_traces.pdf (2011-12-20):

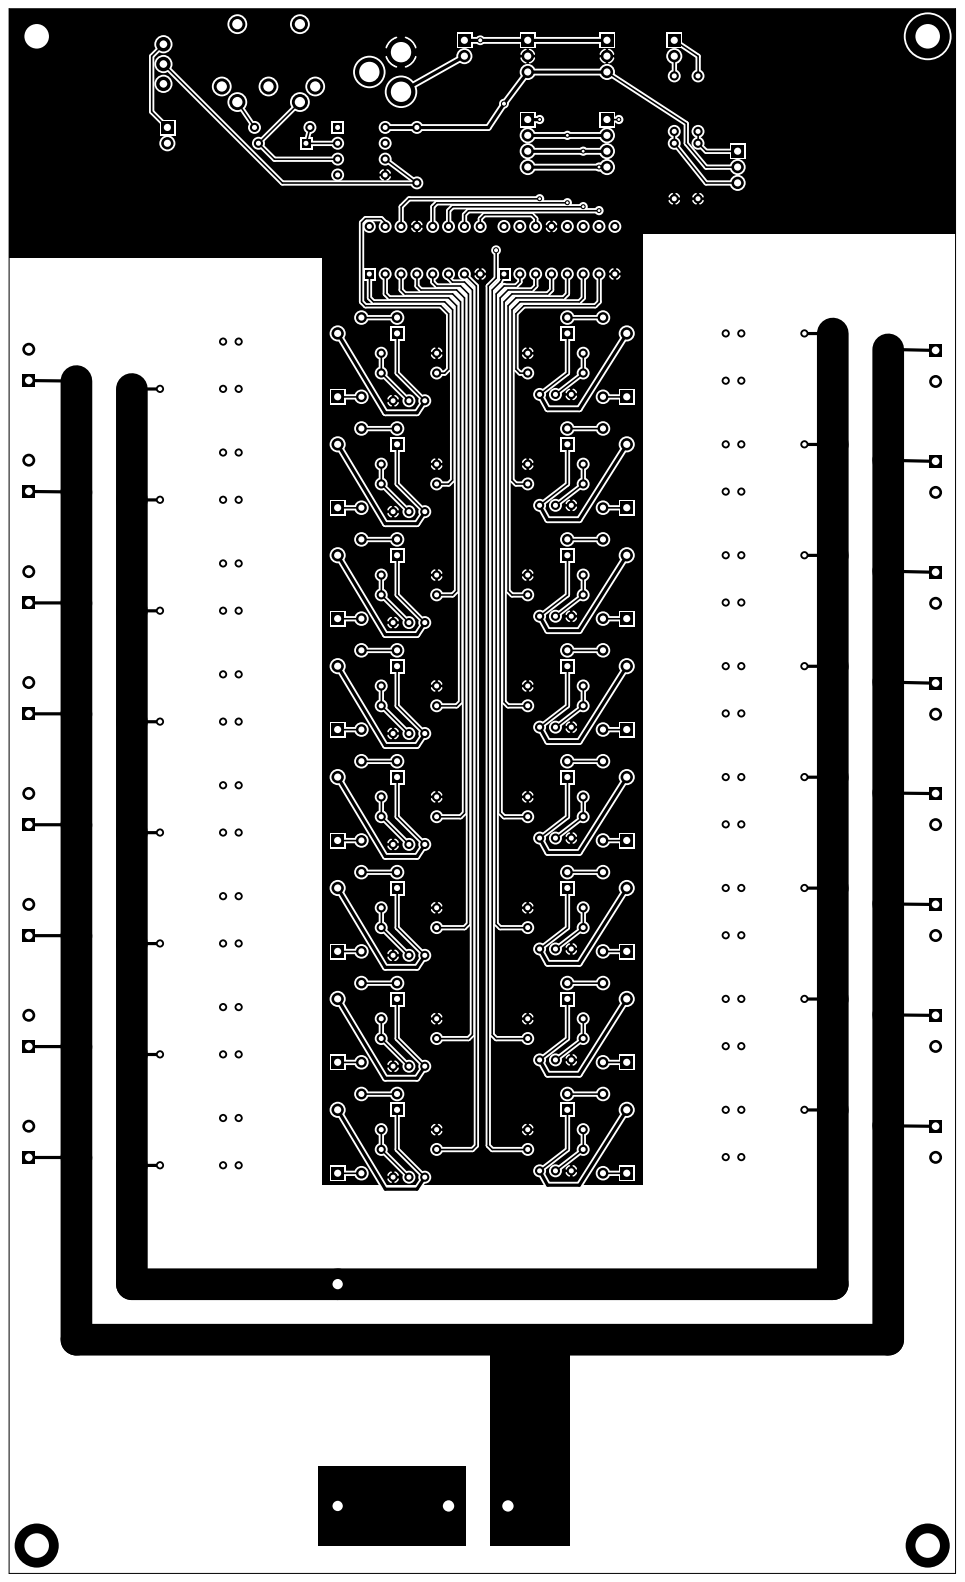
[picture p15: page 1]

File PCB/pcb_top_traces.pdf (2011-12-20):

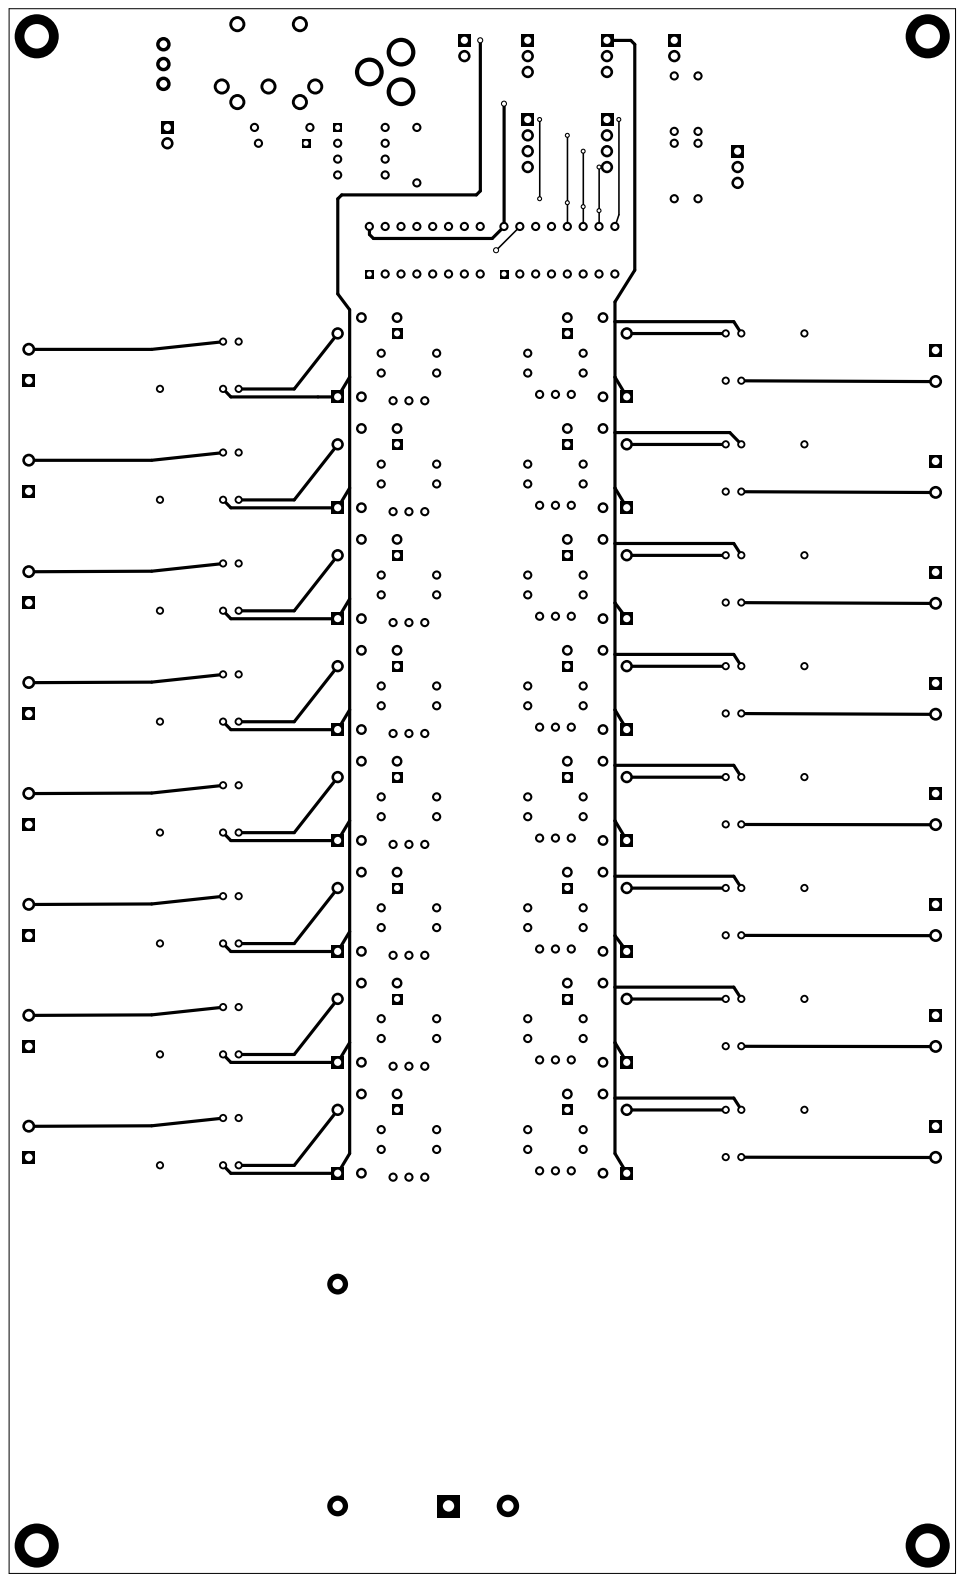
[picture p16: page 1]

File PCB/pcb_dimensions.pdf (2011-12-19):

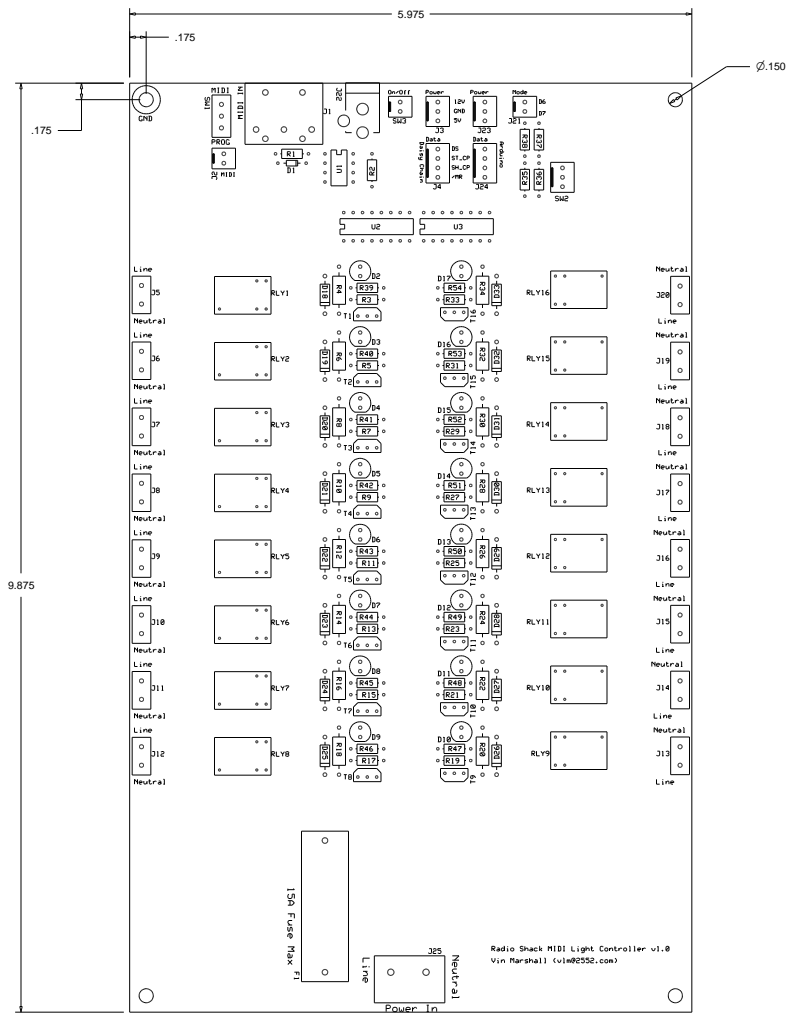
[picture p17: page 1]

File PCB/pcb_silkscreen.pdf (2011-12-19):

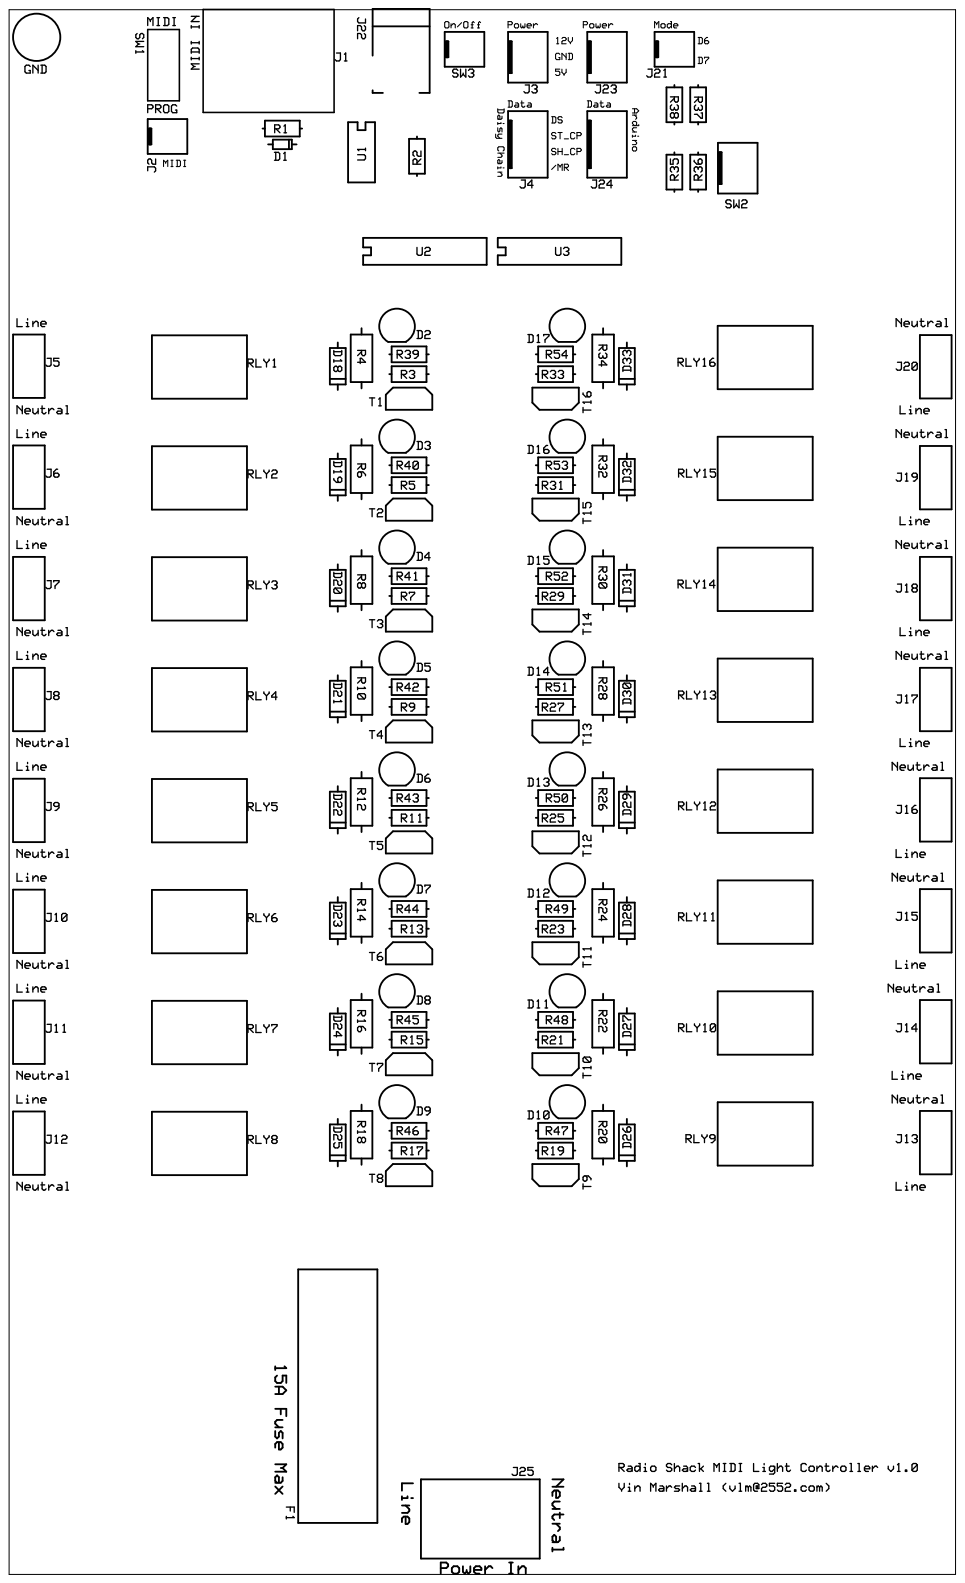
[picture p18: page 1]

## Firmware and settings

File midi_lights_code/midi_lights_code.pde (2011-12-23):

#include <MIDI.h>

/*
 * Radio Shack MIDI Lights
 *
 * Use a MIDI input to sequence strings of holiday lights.
 * 
 * This is the code for the project featured in the December 2011 issue
 * of Popular Science.
 *
 * Check the Github repository for the most recent version of this file
 * https://github.com/vinmarshall/Radio-Shack-MIDI-Lights
 *
 */
 
/* Debugging settings
 * 0 - regular mode - no debugging
 * 1 - Cycle through the relays - 1 to 16 and back
 * 2 - Blink all relays at once - on for 15 seconds, off for 15 seconds
 * 3 - Turn all relays on.
 */
#define DEBUG 0

/*
 * Pin Assignments
 */

// Shift Register Pin Assignments
const int latchPin = 4;  // ST_CP pin of the 74HC595s
const int clockPin = 3;  // SH_CP pin of the 74HC595s
const int dataPin = 5;   // DS pin of the first 74HC595
const int clearPin = 2;  // /MR pin of the 74HC595s

// MIDI Setup
// Connect MIDI IN to RX (Arduino D0).  No assignments necessary.

// Selector Switch Pin Assignments
const int playModePin = 6;  // From one side of the mode selector toggle switch
const int recModePin = 7;   // From the other side of the mode selector switch

// Status LED Pin Assignment
const int statusLED = 13;


/*
 * Globals
 */

// Mode selection 
#define MODE_LIVE 0  // 0 -> Live play mode
#define MODE_REC  1  // 1 -> Recording mode
#define MODE_PLAY 2  // 2 -> Playback mode
int mode = 0;        // Indicates the position of the mode selector switch
int lastMode = 0;
int lastModeState;   // For switch debouncing
unsigned long debounceTime;
unsigned long debounceInterval = 50;

// currentNotes holds the current notes being played or recorded.
// Each bit in the int corresopnds to one relay. 
// e.g. 0x0001 -> relay 1, 0x0002 -> relay 2, 0x0004 -> relay 3, etc...
int currentNotes = 0;

// Note Adjustment - move middle C, #60 in MIDI, down to relay #8
#define NOTE_ADJUSTMENT 53

// Recording setup
#define NUM_TIME_WINDOWS 500
int recordedNotes[NUM_TIME_WINDOWS];  // an array of currentNotes
int recPtr = 0;   // where we are in the recordedNotes array
int lastPtr = 0;  // where recPtr was at the end of the recording

// Number of milliseconds in a recording time window. (resolution)
// A smaller number gives you a greater resolution, but shorter recording time
// Start with this somewhere between 100 and 250
#define INTERVAL 100 
// start time in millis of the current recording window
unsigned long intervalStart = 0;  

void setup() {
  // Setup shift register pins.
  pinMode(latchPin, OUTPUT);
  pinMode(clockPin, OUTPUT);
  pinMode(dataPin, OUTPUT);
  pinMode(clearPin, OUTPUT);

  // Setup the mode selector toggle switch pins
  pinMode(playModePin, INPUT);
  pinMode(recModePin, INPUT);

  // Setup the status LED pin
  pinMode(statusLED, OUTPUT);

  // Clear the shift registers by bringing /MR LOW
  digitalWrite(clearPin, LOW);
  delay(50);
  digitalWrite(clearPin, HIGH);

  // Blink all of the lights on startup.
  for (int i = 0; i < 3; i++) {
    blink(500);
  }

  // MIDI setup
  MIDI.begin(); 
}


void loop() {

  /* 
  * DEBUG Mode - 
  * 
  * If we're in any of the debug modes, we jump out to a separate loop.
  * This will not return control to the main loop.
  */
  if (DEBUG == 1) {
    debugPlayScale(); // This does not return.
  } else if (DEBUG == 2) {
    debugBlink();     // This does not return.
  } else if (DEBUG == 3) {
    debugOn();        // This does not return.
  }

  /*
  * Determine in which mode we are operating
  *
  * playModePin = 0, recModePin = 0  --> Live play mode.  Play the MIDI
  *   input through to the lights without recording.
  * playModePin = 0, recModePin = 1  --> Record mode.  Play the MIDI 
  *   input through to the lights while recording it until the memory is 
  *   full or the mode is changed.
  * playModePin = 1, recModePin = 0  --> Playback mode.  Loop through the 
  *   recorded sequence.
  * playModePin = 1, recModePin = 1  --> Invalid input.  The circuit's 
  *   configuration will prevent this. 
  */

  // Mode switch read and debounce code.
  int playModeReading = digitalRead(playModePin);
  int recModeReading = digitalRead(recModePin);
  int modeReading = recModeReading + (playModeReading << 1);

  // Mark the time of this switch change
  if (modeReading != lastModeState) {
    debounceTime = millis();
  }

  // Switch change is valid if a debouncing interval has passed since last change
  if ((millis() - debounceTime) > debounceInterval) {
    mode = modeReading;
  }

  // Record this reading so we can compare switch positions the next time through
  lastModeState = modeReading;
 
  // if the mode has just changed, do some initializations
  if (lastMode != mode) {
    // Clear whatever notes are on.
    currentNotes = 0x0000;

    if (lastMode == MODE_REC) {
      // Mark where in the buffer this recording ended
      lastPtr = recPtr;
    }
    if (mode == MODE_REC || mode == MODE_PLAY) {
      // reset the buffer pointer when entering record or play mode
      recPtr = 0;
    }

    // log the change
    lastMode = mode;
  }


  if (mode == MODE_LIVE || mode == MODE_REC) {

    /* 
     * If we are in LIVE or RECORD mode, look for a MIDI input 
     */

    // Get a note if one is one is present.
    if (MIDI.read()) {
      switch(MIDI.getType()) {
      case NoteOn: 
        {
          int note = MIDI.getData1();
          int velocity = MIDI.getData2();
          // translate the note into our 16 note system
          // convert middle C (note 60 in MIDI) into relay #8 in our system
          note = note - NOTE_ADJUSTMENT;
        
          // if velocity is greater than 0, this is a note ON
          // otherwise it's actually another form of note OFF
          if (velocity > 0) {
            noteOn(note);
          } else {
            noteOff(note);
          }
          break;
        }
      case NoteOff:
        {
          // Turn notes off for any NoteOff message
          int note = MIDI.getData1();
          note = note - NOTE_ADJUSTMENT;
          noteOff(note);
          break;
        }
      }
    }


    /* 
     * If we're in Recording mode and another time window has passed, 
     * record these notes. 
     */
    if (mode == MODE_REC && (millis() - intervalStart) >= INTERVAL) {
   
      // Record the current notes if the buffer isn't full yet
      if (recPtr < NUM_TIME_WINDOWS) {
        recordedNotes[recPtr++] = currentNotes; // grab the note(s)
        intervalStart = millis(); // restart the interval counter 
        toggleStatusLed();        // flash the metronome / alive LED
      }
    }  
  
  } else {

    /*
     * Otherwise, we are in Playback mode. 
     * We will loop over the notes in the recorded buffer.
     */

    if (millis() - intervalStart >= INTERVAL) {

      // Reset the array pointer if we've reached the end of the recording
      if (recPtr >= lastPtr) {
        recPtr = 0;
      }

      // Set currentNotes to the notes in this window of the recording buffer
      currentNotes = recordedNotes[recPtr++];

      // toggle the metronome/alive LED
      toggleStatusLed();

      // And reset the interval counter
      intervalStart = millis();
    } 
  }  


  /* 
   * "Play" the notes current showing in currentNotes - 
   * either those just played in or those from the recording.  
   *
   * Stop playing notes when the recording buffer is full.
   */
  if (mode == MODE_REC && recPtr >= NUM_TIME_WINDOWS) {
    // Don't play notes - alert user recording buffer is full
    currentNotes = 0x0000;
  }
    
  doOutput();

}

/*
 * doOutput() 
 *
 * Set the relays to the current notes being played or played back.
 * Shifts the two bytes of currentNotes int out into the shift registers
 *
 */
void doOutput() {
  digitalWrite(latchPin, LOW);  // Disable register output changes
  shiftOut(dataPin, clockPin, MSBFIRST, currentNotes >> 8);
  shiftOut(dataPin, clockPin, MSBFIRST, currentNotes);
  digitalWrite(latchPin, HIGH);  // Latch new data to the register outputs
}

/* 
 * void noteOn(int note)
 * 
 * Turns on the note in our representation of the notes currently being 
 * played or played back.
 *
 */
void noteOn(int note) {
  if (note >= 0 && note < 16) {
    currentNotes |= 1<<note;
  }
}
 
/*
 * void noteOff(int note)
 *
 * Turns off the note in our representation of the notes currenting 
 * being played or played back.
 *
 */
void noteOff(int note) {
  if (note >= 0 && note < 16) {
    currentNotes &= ~( 1<<note);
  }
}
 
/*
 * blink(int pause)
 * 
 * Does just what it says - blinks the lights with the specified pause
 * in between.
 */
void blink(int pause) {
  currentNotes = 0xFFFF;    // Turn ON
  doOutput();
  delay(pause);
  currentNotes = 0x0000;    // Turn OFF
  doOutput();
  delay(pause);
}

/*
 * toggleStatusLed()
 * 
 * Toggles the status LED on and off
 * 
 */
void toggleStatusLed() {
  int status = digitalRead(statusLED);
  (status == 1) ? status = LOW : status = HIGH;
  digitalWrite(statusLED, status);
}
 
/*
 * debugPlayScale()
 *
 * Debugging mode.  Cycles up and down through all of the relays - 1 to 16
 * and back.  This method loops here and does not return to the main loop.
 *
 */
void debugPlayScale() {

  // Loop endlessly
  while (1) {
    
    // Cycle up - relay 1 to 16
    for (int i=0; i < 16; i++) {
      noteOn(i);
      doOutput();
      delay(250);
      noteOff(i);
      doOutput();
    }
    
    // and back down
    for (int i=14; i > 0; i--) {
      noteOn(i);
      doOutput();
      delay(250);
      noteOff(i);
      doOutput();
    }
  }
}

/* 
 * debugBlink()
 *
 * Debugging mode.  Flashes all relays on for 1 second, off for 1 second.
 * This method loops here and does not return to the main loop.
 *
 */
void debugBlink() {
  
  // Loop endlessly
  while (1) {
    blink(1000);
  }
}

/*
 * debugOn()
 *
 * Debugging mode.  Turns all relays on.
 * This method loops here and does not return to the main loop.
 *
 */
void debugOn() {
  currentNotes = 0xFFFF;
  doOutput();
  while (1) {}
}

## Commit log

2011-12-15 Added initial version of the PCB files
    [rs_midi_lights.sch]
2011-12-15 updated schematic and board - added 100K pulldown resistor to relay's transistor base and moved LED to be powered with relay coil. And added the missing diodes across the relay coils
    [rs_midi_lights.sch]
2011-12-15 Added schematic images to ./schematic directory
2011-12-15 Added ExpressPCB custom components files used in the schematic and pcb design.
2011-12-15 Arduino code v0.1
2011-12-16 Revised Ordering BOM
    [ordering_BOM.ods]
2011-12-16 Added .XLS versions of BOM files
    [circuit_board_BOM.xls, ordering_BOM.xls]
2011-12-19 Revised schematic to include poer busses
    [rs_midi_lights.sch]
2011-12-19 Updated PCB
2011-12-19 Added images and mechanical drawings of the PCB
    [pcb_mechanical.dxf]
2011-12-19 Added Line/Neutral labels to every terminal block.
    [pcb_mechanical.dxf]
2011-12-19 Added fuse, fuse holder, and input power terminals to BOM
    [circuit_board_BOM.ods, circuit_board_BOM.xls, ordering_BOM.ods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]
2011-12-19 Added labBOM name for lighting power input terminals
    [rs_midi_lights.sch]
2011-12-20 Enlarged mounting hold pads to 0.275'' dia to clear the 0.260'' heads of the #6-32 screws
2011-12-23 Updated Arduino code
2012-02-07 added switch jumpers to ordering BOM
    [ordering_BOM.ods, ordering_BOM.xls]
